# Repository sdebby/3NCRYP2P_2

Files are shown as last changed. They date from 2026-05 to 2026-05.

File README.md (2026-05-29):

# LoRaCore - 3NCRYP2P V2

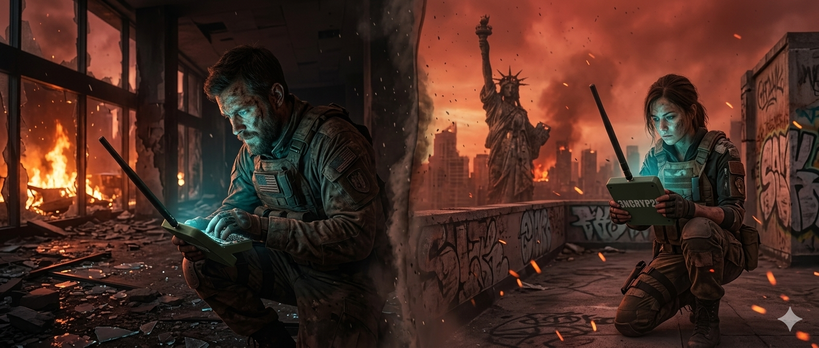
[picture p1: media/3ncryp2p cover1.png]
Overview picture


**When the towers fall, the grid dies, and the satellites stop answering, two of these still talk to each other.**

## Overview

This repository is the forking UPGRADED from the original [sdebby/3NCRYP2P](https://github.com/sdebby/3NCRYP2P) project, refactored under the working name **LoRaCore**.

LoRaCore is the firmware for **3NCRYP2P** (ENCRYPT P2P) - a portable, off-grid, end-to-end encrypted peer-to-peer messaging terminal. It is built around the ESP32-C6, an SSD1306 OLED, a CardKB keyboard, and a 433 MHz LoRa transceiver. No cell tower. No internet. No cloud account. No subscription. Two devices, a pair of public keys, and validated 1.5 km in metropolitan .

---

## In a nutshell

- **Encrypted text messaging over LoRa** at 433 MHz, AES-256 in CTR mode, with HMAC-SHA256 message authentication.
- **Diffie-Hellman key exchange (Curve25519)** so the long-term shared secret is never transmitted, never stored on memory in plaintext, and never reused between sessions.
- **Pairing over ESP-NOW**, a short-range link used only at first introduction. The plaintext public keys and MAC are exposed only to anything within roughly 100 metres line-of-sight in that brief window.
- **At-rest hardening**: the remote device's MAC is persisted only as a salted SHA-256 digest. A flash dump alone does not yield the peer identity or a usable HMAC input.
- **Replay and tamper resistance** through random 16-byte IVs per packet and HMAC verification on every frame, including ACKs.
- **Brute-force lockout**: 10 consecutive HMAC failures permanently lock the device until the operator resyncs keys.
- **Reliable delivery** via a 3-attempt retry loop with 2 second ACK timeout per attempt.
- **Local UI**: 128x64 OLED with 20-line scrollback, full QWERTY input via CardKB, scroll using Up/Down keys, dedicated Fn+K key combination to re-pair.

## MRD (Marketing Requirement)

- Provide a simple, secure, and portable LoRa-based communication terminal.
- Support up to *20* lines of message history on a compact OLED display.
- Enable secure key exchange and encrypted messaging between devices.
- Top notch security using AES-256 in CTR mode, with HMAC-SHA256 message authentication, Diffie-Hellman key exchange (Curve25519) and short range MAC address exchange.
- Allow easy user input and message reading.
- Feedback for system status and errors using debug.
- Military look-alike enclosure 😊.

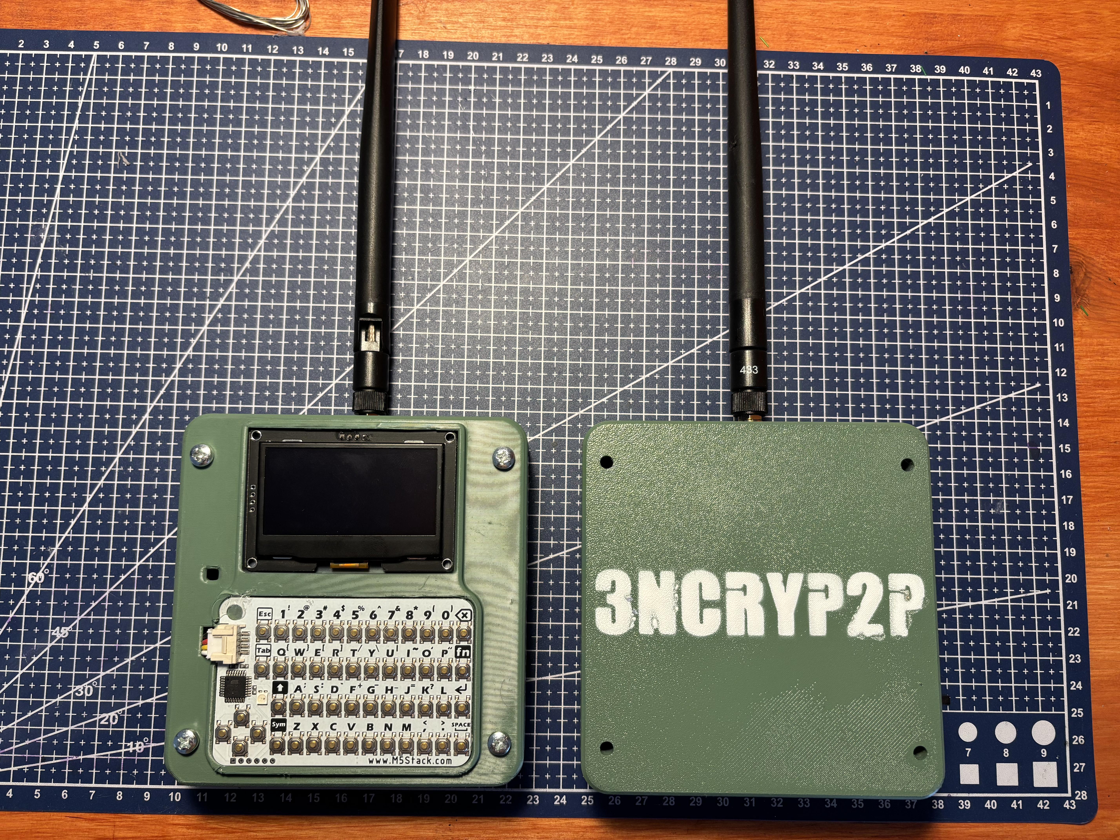
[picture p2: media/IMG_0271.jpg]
Device Overview

 
 ## Skill Set

- Embedded C++ programming (Arduino/ESP32).
- LoRa wireless communication.
- ESP NOW communication protocol.
- Cryptography (AES256 CTR, Diffie-Hellman, HMAC, Hasing remote MAC address).
- 3D design.
- 3D printing and painting.

## Setup (Software Setup)

**Hardware Requirements:**
| Component | Detail |
|---|---|
| MCU | ESP32-C6 |
| Radio | LoRa SX1278 module, 433 MHz |
| Display | SSD1306 OLED, 128 x 64 px, I2C address 0x3C |
| Keyboard | M5Stack CardKB, I2C address 0x5F |
| Status LED | Builtin LED |
| Enclosure | PETG 3D-printable - design using Fusion 360, source files in `CAD/` |

## BOM (Bill Of Materials):

**For production:**
1. ESP32 C6 dev kit
2. [LoRa RA02](https://docs.ai-thinker.com/_media/lora/docs/c048ps01a1_ra-02_product_specification_v1.1.pdf) (433 MHz module)
3. [SSD1306 OLED - 2.24 inch I2C](https://tcclcd.en.made-in-china.com/product/swOajivDfxpf/China-2-42-Inch-128-64-LCD-SSD1309-Driver-Yellow-Monochrome-OLED-Display.html) (128x64 pixels, I2C)
4. [CardKB keyboard](https://docs.m5stack.com/en/unit/cardkb_1.1) (I2C)
5. [Charger panel](https://www.aliexpress.com/item/1005005037876729.html?spm=a2g0o.order_list.order_list_main.386.6b881802CcDzO8)
6. [433 MHz antenna] (https://he.aliexpress.com/item/1005009824013771.html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).
7. LiPo battery 850 mAh.
8. On/Off switch.
9. Custom PCB manufacturing using JLCPCB.
10. 3D printing for enclosure.
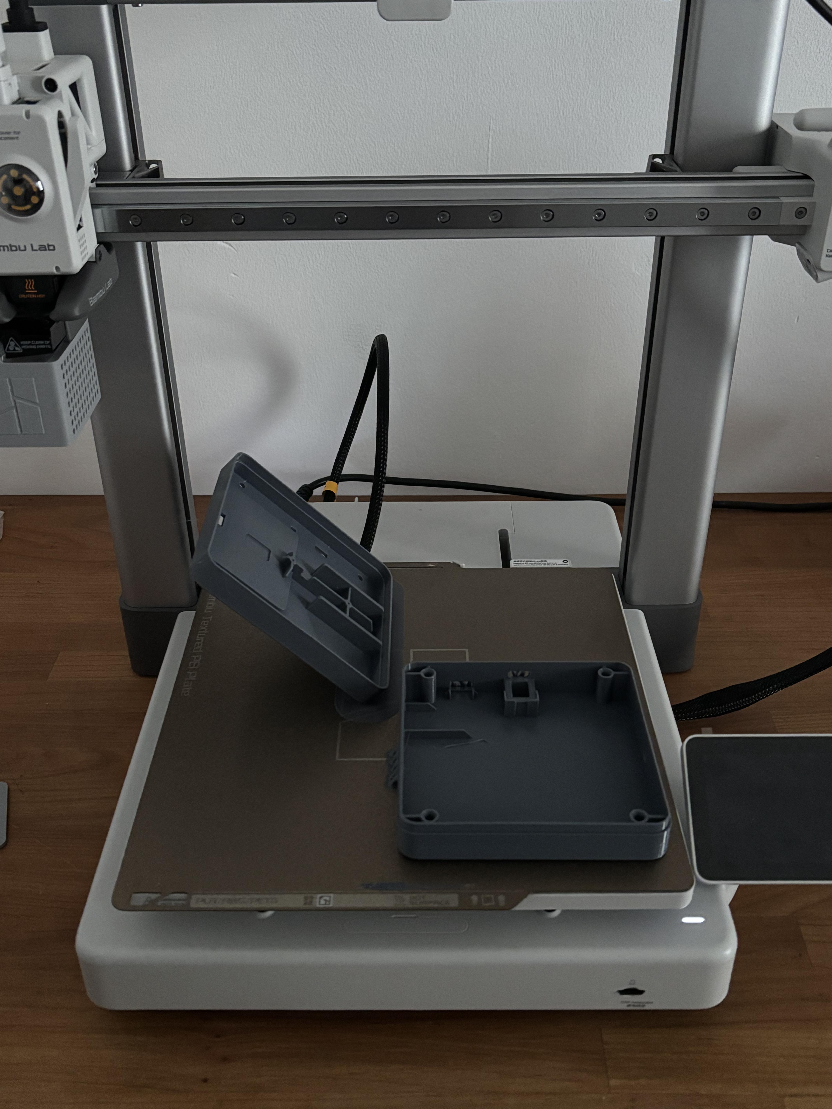
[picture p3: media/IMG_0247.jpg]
3D printing enclosure - from PETG


## Cryptographic stack

```
Pairing  : Curve25519 ECDH  ->  shared secret  ->  SHA-256  ->  32-byte session key (HashSecret)
Identity : SHA-256( MAC || HashSecret )  -> 32-byte salted MAC digest, persisted in NVS
Confidentiality : AES-256-CTR( HashSecret, random 16-byte IV per packet )
Integrity / authenticity : HMAC-SHA256, key = HashSecret, input = ciphertext || IV || senderMacDigest
ACK integrity : HMAC-SHA256 over the 3-byte return code, same key derivation
Replay defence : fresh random IV per packet, included in HMAC input
Lockout : 10 consecutive HMAC failures sets DevLock = true in NVS, requires re-pair
```

The session key (`HashSecret`) is held in RAM only. It is never written to flash. A power cycle on either device forces a fresh handshake over LoRa using the previously paired peer, and a Fn+K from the operator forces a full re-pair over ESP-NOW.

---

## LoRa packet format

```
[Setup 1B] [PayloadSize 1B] [Payload N B] [IV 16B] [HMAC 32B]
```

| Setup bit | Meaning |
|---|---|
| 0 | Handshake - public key + sender MAC + key-return flag |
| 1 | Test message - decryption sanity check after handshake |
| 2 | Encrypted user message |
| 3 | ACK / NACK - return codes 200 OK, 502 NACK, 500 RESYNC |

---

## File map

| File | Role |
|---|---|
| `LoRaCore.ino` | Main entry. Defines globals, pinout, screen and keyboard setup, the state machine, the `setup()` and `loop()` functions, keyboard handling (Enter, Backspace, Up, Down, Fn+K, Fn+D), the ESP-NOW broadcast peer class, the boot-time decision tree between fresh pairing and resuming an existing pair, and the optional Auto Interval Messages debug sender. |
| `LoRaHelper.ino` | Everything LoRa: radio parameter setup (frequency, bandwidth, spreading factor, coding rate, sync word, TX power), `SendLoRaPayload` for encrypting and transmitting a frame, `SendWithRetry` for the 3-try / 2 s ACK loop, `TransmitLoRaPayload` and `TransmitLoRaACK` and `TransmitLoRaHandshake` for the wire-format writers, and the receive-side `onReceive` switch that dispatches handshake, test, encrypted, and ACK frames - including HMAC verification, lockout counter, and ACK reply. |
| `EncryptHelper.ino` | All cryptographic primitives: Curve25519 keypair generation (`CalcKeys`), peer key processing and shared-secret computation (`computeSharedSecret`, `RemoteKeyReceivedProcess`), session-key derivation via SHA-256 (`CalculHashSecret`), random IV generation, AES-256-CTR encrypt and decrypt, and the raw HMAC-SHA256 calculation. |
| `EspNowHelper.ino` | Short-range pairing transport: Wi-Fi STA setup on channel 6, `ExchangePublicKeysESPNOW` which broadcasts the local public key up to `KeySendTries` times on a 2 s scheduler, and the post-pairing trigger that fires the LoRa test payload from whichever peer has the larger MAC (deterministic tie-break to prevent both devices transmitting simultaneously). |
| `displayHelper.ino` | OLED rendering: display init, `printSCR` which prefixes outgoing (`->`), incoming (`<-`), and system (`* `) messages and word-wraps them into the 20-line scrollback buffer, scroll-up and scroll-down for history navigation, the input-line separator, and the boot logo. |
| `generalHelpers.ino` | Persistence, identity, and integrity glue: NVS preferences setup under namespace `3NCRYPT2P`, legacy migration that strips any plaintext `RemoteMAC` key, the lockout loop that drives the LED red and halts the device, the salted MAC hashing function, the HMAC input builder (ciphertext || IV || macDigest), and the local MAC reader. |
| `Jurnal.md` | Development journal. Chronological design notes from March 2025 onwards: why ESP-NOW was picked over Zigbee, Thread, NFC, BLE and serial; the move from a hardcoded key to Curve25519 ECDH; the move from SHA-256 message digests to HMAC-SHA256; the move from AES-128 to AES-256; the hybrid pair-once-over-ESP-NOW, rekey-each-boot-over-LoRa scheme; bug fixes and feature additions through to spring 2026. |
| `CAD/` | 3D-printable enclosure parts. SolidWorks part file and neutral STEP export for the 2.42-inch OLED carrier. |
| `CLAUDE.md` | Internal project notes used by AI assistants when working on this codebase. Not required for build. |

---

## Build and flash

1. Clone or download this repository.
2. Install the **Arduino IDE** with **ESP32 board support**.
3. Install these libraries through the Library Manager:
   - `LoRa` (Sandeep Mistry)
   - `Adafruit SSD1306` and `Adafruit GFX`
   - `Adafruit NeoPixel`
   - `Crypto` (provides `Curve25519.h`, `SHA256.h`, `AES.h`, `CTR.h`)
   - `ptScheduler`
1. Open `LoRaCore.ino` in the Arduino IDE. The other `.ino` files in this folder are picked up automatically as part of the same sketch.
2. Select board: **ESP32-C6 Dev Module**.
3. Optional: set **Tools -> Core Debug Level -> Debug** to enable the verbose serial console (`Consl = true`) and accept text input over the serial port instead of the keyboard.
4. Compile and upload. Repeat for the second unit.

---

## First-time pairing

1. Power on both devices in the same room.
2. With no remote stored in NVS, each device automatically enters ESP-NOW broadcast mode and exchanges public keys.
3. The device with the larger MAC (deterministic, computed from each side's WiFi STA MAC) sends an AES-256 encrypted test payload over LoRa. The receiver decrypts, verifies HMAC, and the screen confirms `Key exchange process success`.
4. Both devices now show `SYSTEM READY!`. The salted remote-MAC digest is written to NVS. The session key lives only in RAM.

To force a re-pair at any time, press **Fn+K** on the keyboard, then press **ENTER** when the remote operator confirms readiness on their unit.

---

## Daily use

| Action | Key |
|---|---|
| Send the typed message | ENTER |
| Delete the previous character | BACKSPACE |
| Scroll back through history | UP arrow |
| Scroll forward through history | DOWN arrow |
| Force a full re-pair (ESP-NOW) | Fn + K |
| Toggle Auto Interval Messages (debug) | Fn + D |

Outgoing messages are prefixed with `->`. Incoming with `<-`. System messages with `* `. Up to 20 lines of history are kept; six lines are visible at a time on the 128x64 display.

---

## Threat model and known weak points

What this device defends against:

- A passive eavesdropper anywhere along the LoRa path. Without `HashSecret` the traffic is AES-256 ciphertext with random IVs.
- An active attacker injecting forged messages. HMAC-SHA256 over ciphertext, IV, and the sender's salted MAC digest will fail verification, the message is dropped, and the failure counter increments.
- A flash-dump attacker with physical access to one device after the fact. Only the salted MAC digest is on disk; the session key is not.
- Brute-force probing. After 10 consecutive HMAC failures the device permanently locks until re-pair.

What this device does **not** defend against:

- An attacker physically present during the **initial ESP-NOW pairing**. Within roughly 100 metres of the pairing event, the public keys and MAC are observable. This is a short, deliberately bounded window. The original 3NCRYP2P also flagged this as the system's Achilles heel; the move from hardcoded keys to ECDH closed the more serious version of that problem, but pairing-time exposure remains.
- A compromised endpoint. If the attacker holds your device while it is unlocked and paired, they hold the conversation.
- Side-channel attacks against the ESP32-C6 itself.
- Direction-finding. LoRa transmissions are emissions; they can be located by anyone with an SDR and patience. Encryption protects content, not the fact that you are transmitting.

Plan accordingly.

---

## Range

Tested up to **1.5 km** in  urban conditions with the parameters in this firmware. Open terrain, elevation on either end, or a directional antenna will extend that. Heavy concrete, dense forest, or a hill in the middle will shorten it.

---
## Schematics

Scheme

## PCB

* PCB design using KiCad
* 2 layers PCB, black color.
* PCB manufacturing using JLCPCB
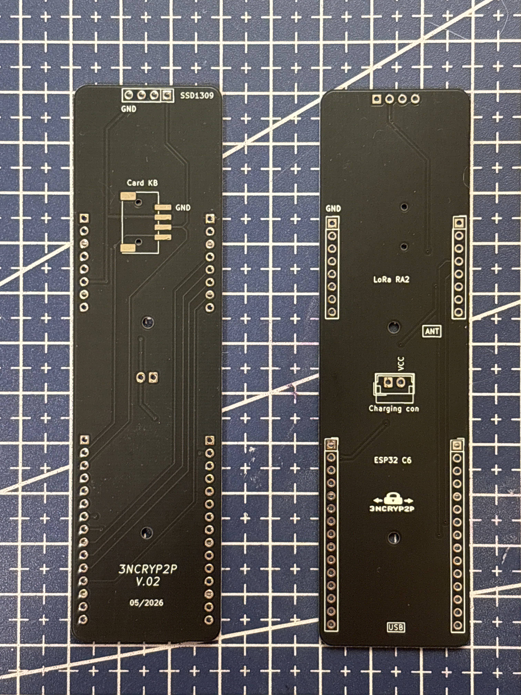
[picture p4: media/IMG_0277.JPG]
Custom PCB

you can download the gerber files from /GERBER Library
---

## Hardware assembly:

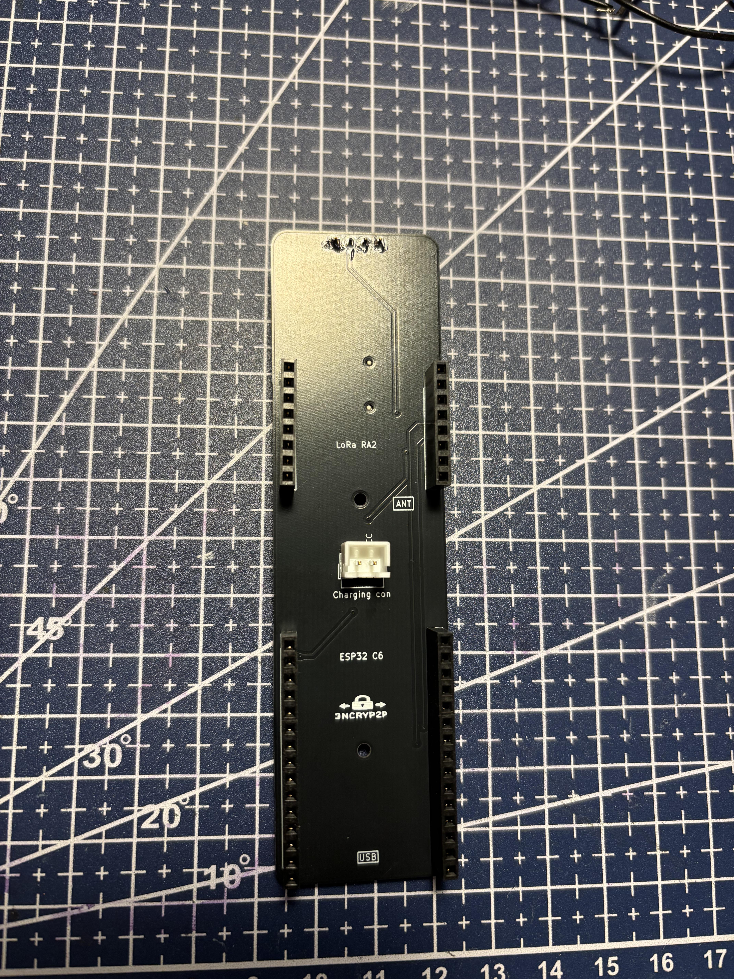
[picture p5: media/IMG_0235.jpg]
PCB Soldering 1


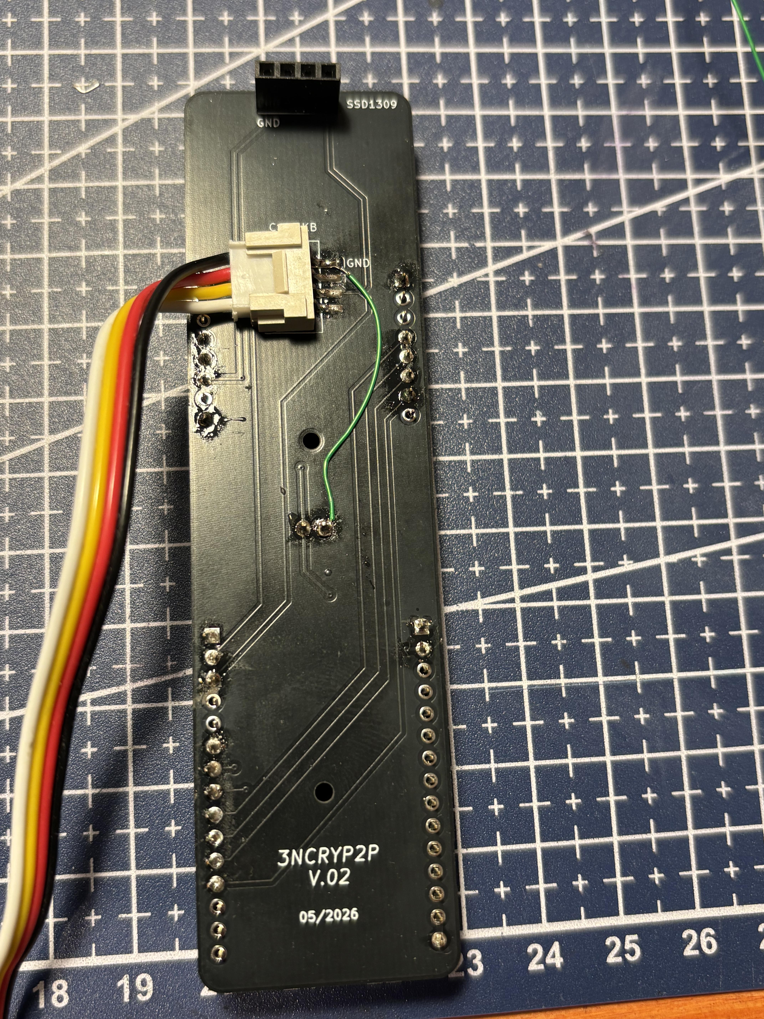
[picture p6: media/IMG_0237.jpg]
PCB Soldering 2


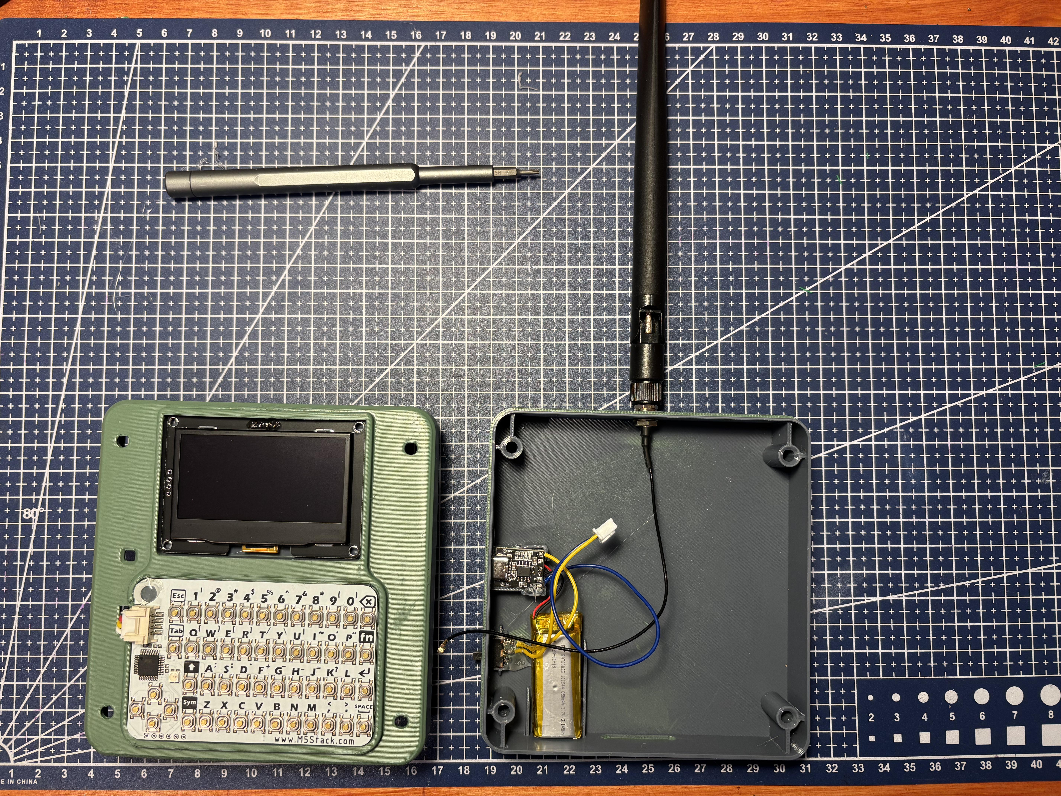
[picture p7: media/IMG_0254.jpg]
Assembly on enclosure 1


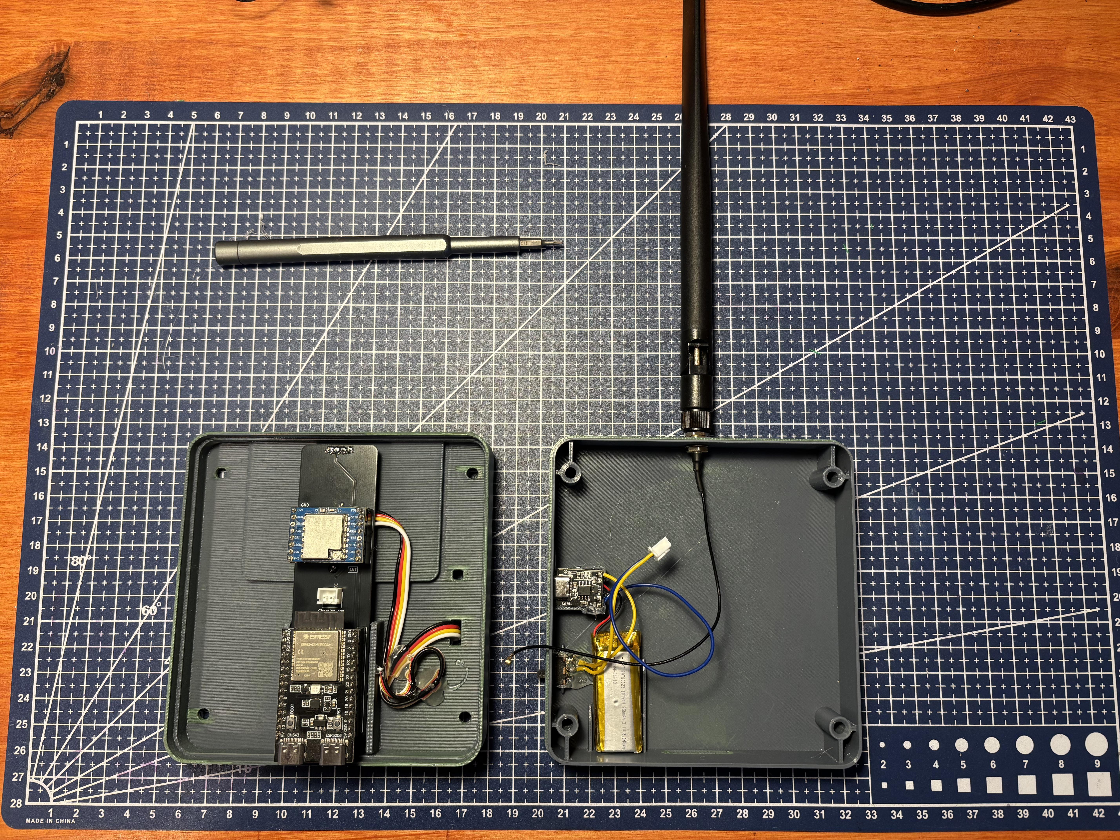
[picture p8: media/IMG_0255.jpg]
Assembly on enclosure 2


### 3D enclosure design

* Using Autodesk Fusion360
* 3D print using Bambulab A1 with PETG filament.
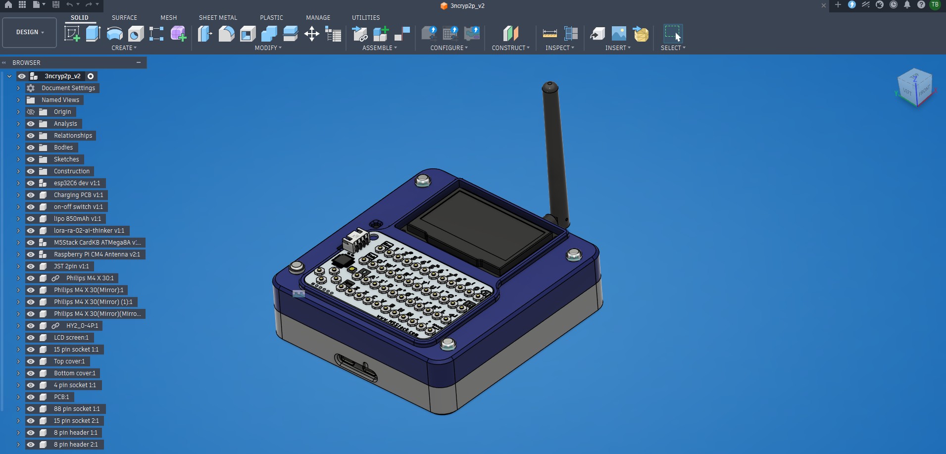
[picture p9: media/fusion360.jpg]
Fusion360 Design

you can download the 3D files from /3D library.

Painting 
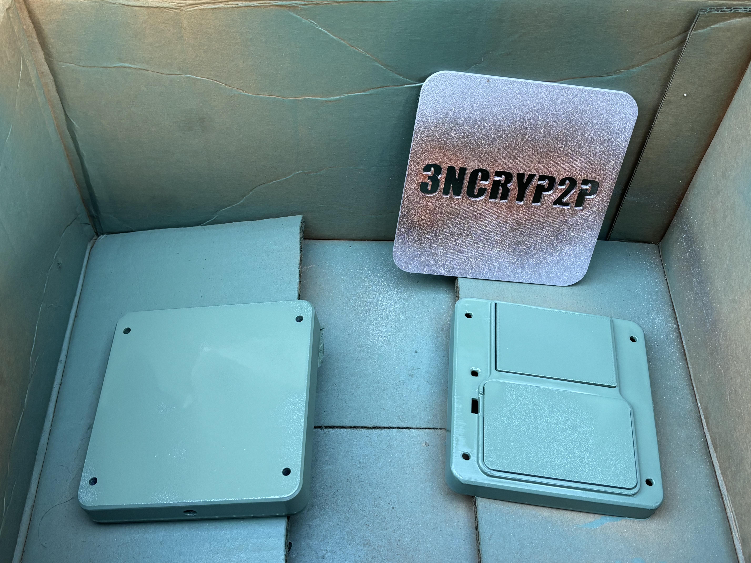
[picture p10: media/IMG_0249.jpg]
Paint 1


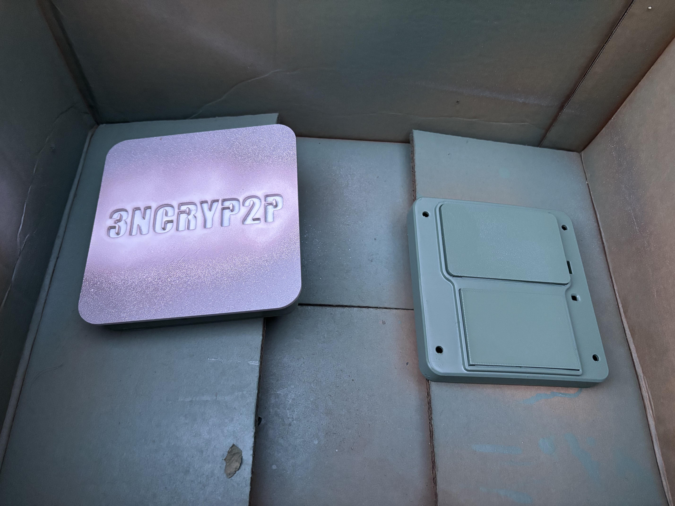
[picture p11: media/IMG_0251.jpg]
Paint 2


## Range test
**Sender**

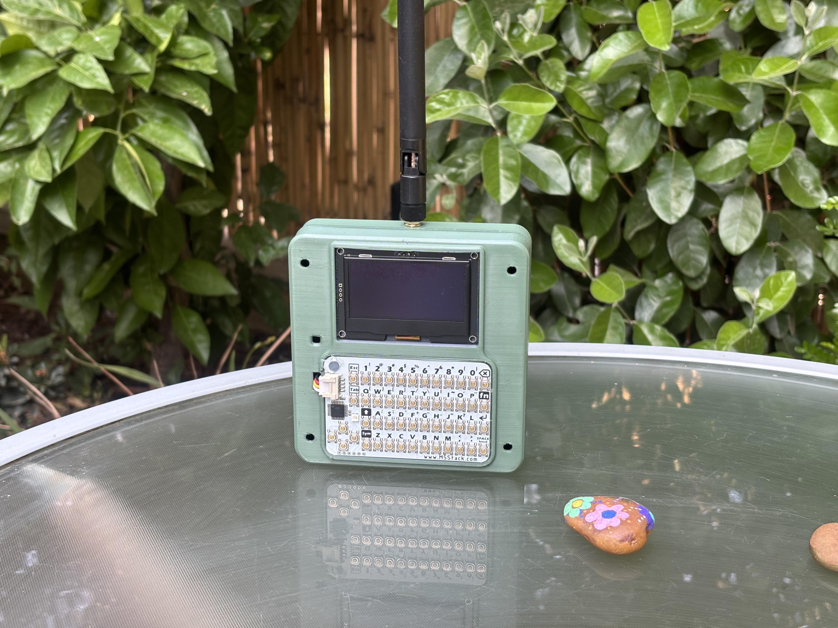
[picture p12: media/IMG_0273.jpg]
Sender


---

**Receiver**

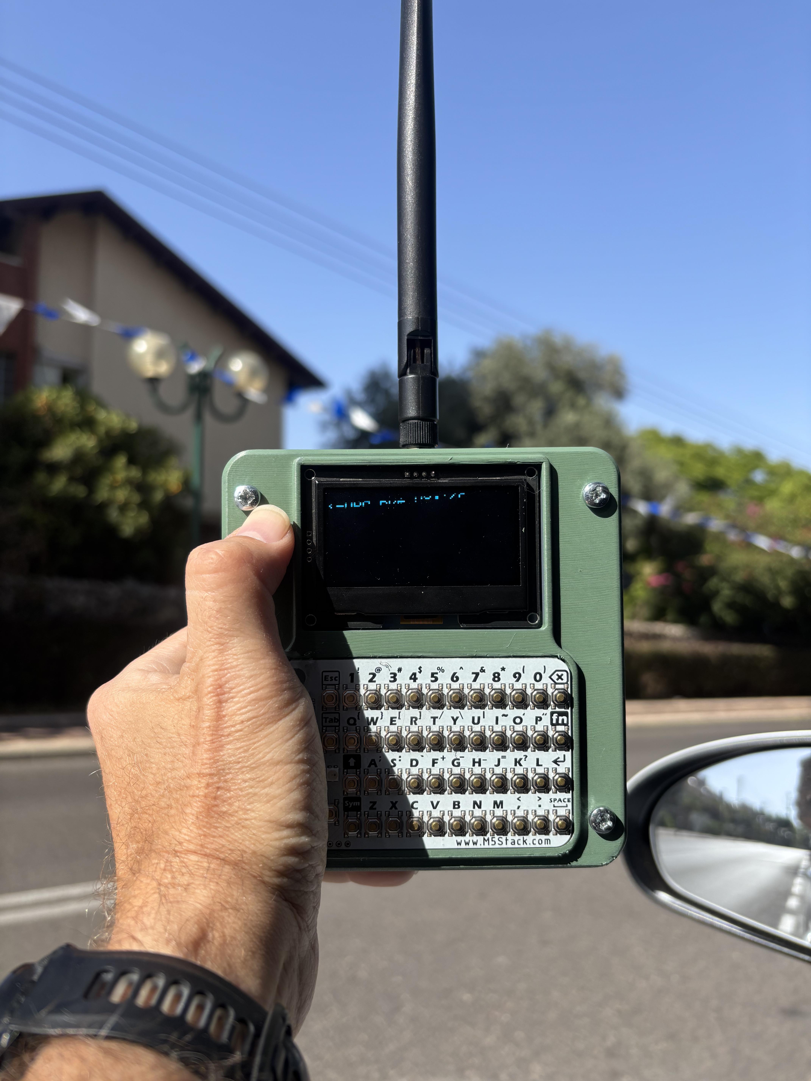
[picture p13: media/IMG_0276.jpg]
Receiver


**Non-line of sight distance** 1.5 Km

## Power consumption

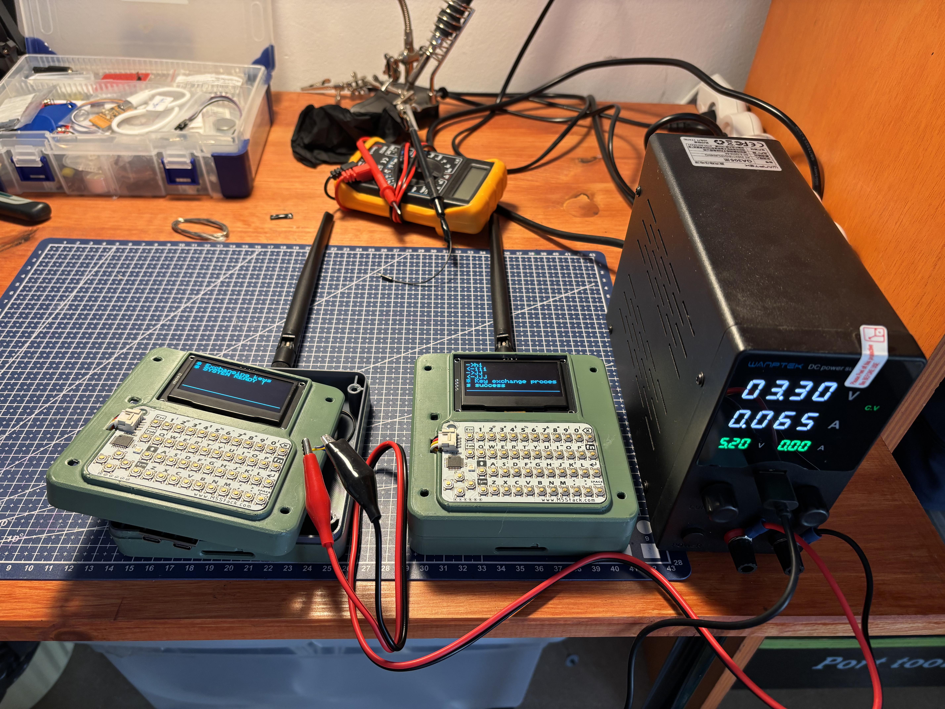
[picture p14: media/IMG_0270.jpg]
Checking power


- Battery capacity: 850 mAh
- Idle current: 65 mA (continuous)
- Hourly burst: +162 mA for 25 s (sending 25 messages an hour)
- Startup: 180 mA for 3 s (one-time) (ESP NOW sync)

Average hourly consumption
65 + 1.125 = 66.125 mAh / hour
Usable capacity after startup: 850 − 0.15 = 849.85 mAh
t = 849.85 ÷ 66.125 ≈ 12.85 hours ≈ 12 h 51 min

**Suggestion for optimization**
putting Display on sleep when ideal.
adding LED to display when new message arrives, then the user will press any button to wake up the screen. 

## Video

(https://youtu.be/NzuQNOC-KOk)

## Compare to 3NCRYP2P V1

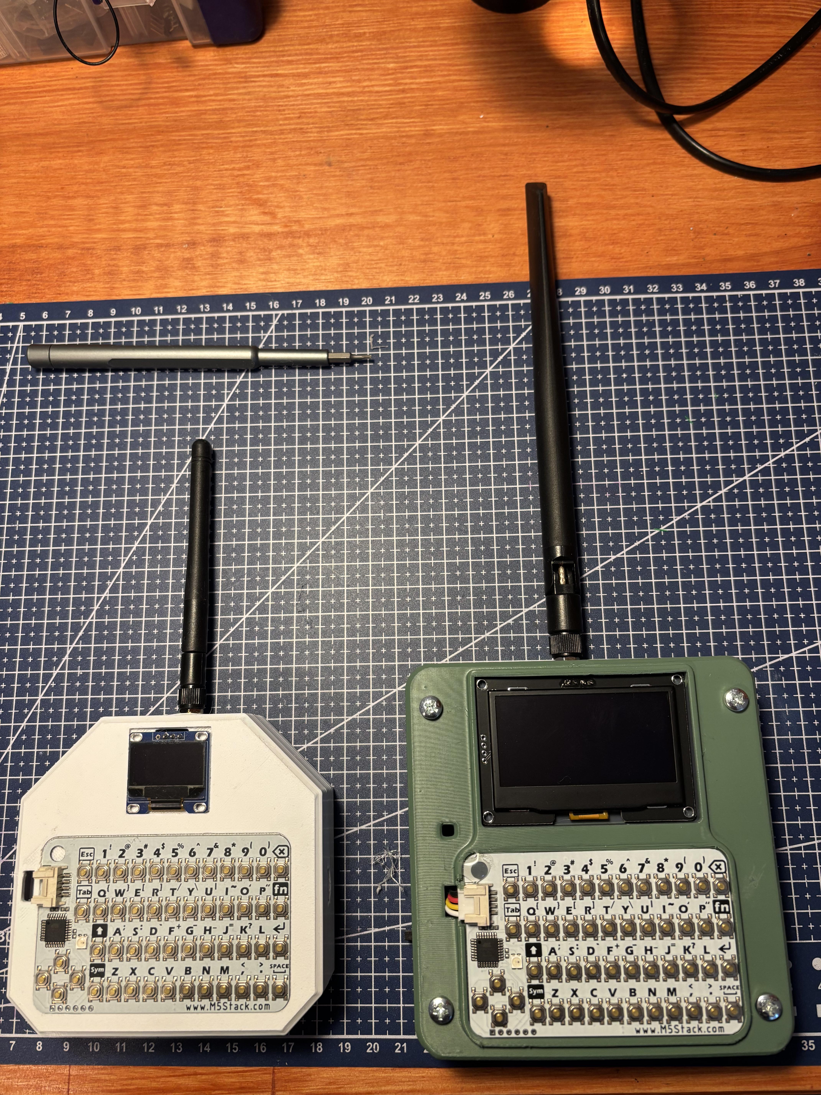
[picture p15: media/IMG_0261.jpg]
Design Compare 1


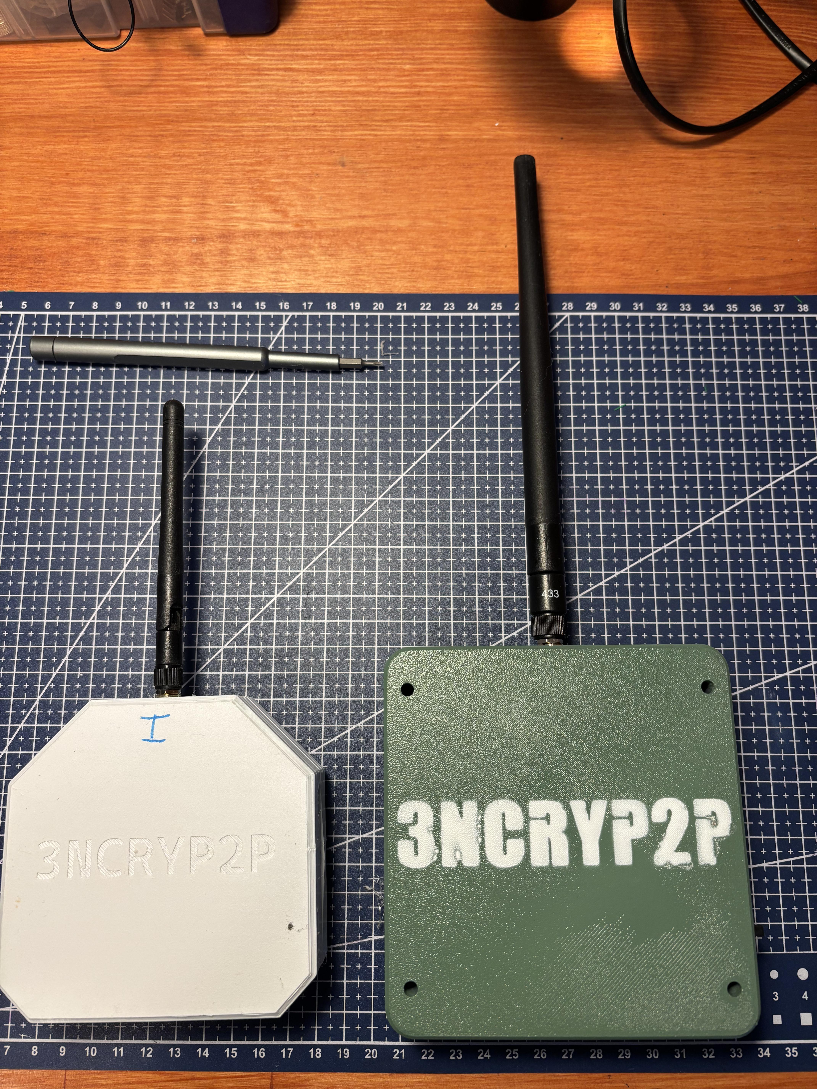
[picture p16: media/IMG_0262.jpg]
Design Compare 2


* BETTER ENCRYPTION - breaking V1 Achilles heel - using AES256 asymmetric key encryption.
* HMAC message validation - including device secret MAC address.
* Device MAC address is exchanged in short range only and hashed in device memory.
* A longer (18 cm with 3dbi gain instead of 9 cm) antenna is improving the range from 500 m in urban area to 1.5 Km.
* Military looking device.
* bigger screen (2.42" instead of 1.3")

## Compare to MESHTASTIC project

[Meshtastic](https://meshtastic.org/)
- LoRaCore is a strict **1:1 encrypted terminal**
- Meshtastic is a **many-to-many community mesh**. The table below summarizes the trade-offs.

### Feature comparison

| Area | LoRaCore (3NCRYP2P V2) | Meshtastic |
|---|---|---|
| Network topology | Strict 1:1 paired devices | Multi-hop mesh, many nodes |
| Key exchange | Curve25519 ECDH at pairing, ephemeral per session | Pre-shared channel key (PSK); x25519 PKC added for DMs in v2.5+ |
| Session key storage | RAM only, never on flash | PSK persisted on flash per channel |
| Confidentiality | AES-256-CTR, random 16 B IV per packet | AES-256-CTR (channels), AES-CCM (DMs since v2.5) |
| Message authentication | HMAC-SHA256 on every packet (incl. ACKs) | None on channel messages; AES-CCM tag on DMs only |
| Sender identity binding | Salted SHA-256 MAC digest mixed into HMAC | None - anyone with PSK can impersonate any node |
| Replay defence | Random IV + HMAC per packet (no counter window) | Packet-ID dedup, short window |
| Forward secrecy | Effective (re-pair regenerates keys, key never written to flash) | None - "Harvest now, decrypt later" is acknowledged in their docs |
| Brute-force lockout | Yes - 10 HMAC failures permanently locks NVS | None |
| At-rest hardening | Only salted MAC digest persisted | PSK, node DB, position history persisted |
| Range per hop | ~1.5 km validated urban, 433 MHz | Similar per hop (varies by band/region) |
| Effective reach | Single hop only | Multi-hop, region-wide with enough nodes |
| Frequency band | 433 MHz (fixed at compile time) | 433 / 868 / 915 MHz, region-configurable |
| User interface | Standalone - built-in OLED + CardKB, no phone needed | Phone app (BLE/Wi-Fi) on most devices; few have native KB/screen |
| Hardware support | One purpose-built ESP32-C6 design | Dozens: T-Beam, Heltec V3, T114, RAK WisBlock, Wio Tracker, etc. |
| Attack surface | LoRa + ESP-NOW only, no IP stack, no BLE, no MQTT | LoRa + BLE + Wi-Fi + MQTT + web admin + OTA |
| Code base size | ~6 short `.ino` files, auditable in an afternoon | Large C++ codebase, many subsystems |
| Ecosystem & community | Personal project, single maintainer | Large open-source community, active CVE tracking |
| Power budget | ~66 mA average, ~12.85 h on 850 mAh | Varies; nRF52 boards (e.g. T114) reach ~11 µA deep sleep |
| Group messaging | Not supported by design | Native - channels and groups |
| GPS / telemetry | Not included | Built-in on many boards (position, battery, env sensors) |
| Setup effort | Two pre-paired units, no config | Phone pairing, channel keys, region selection |

## Next steps
[ ] Increase range with a directional antenna ,higher gain or mesh communication.

[ ] Increase partners.

## A note for whoever finds this later

If you are reading this and the rest of the network is gone, the recipe is in the files.

**Do not panic !**

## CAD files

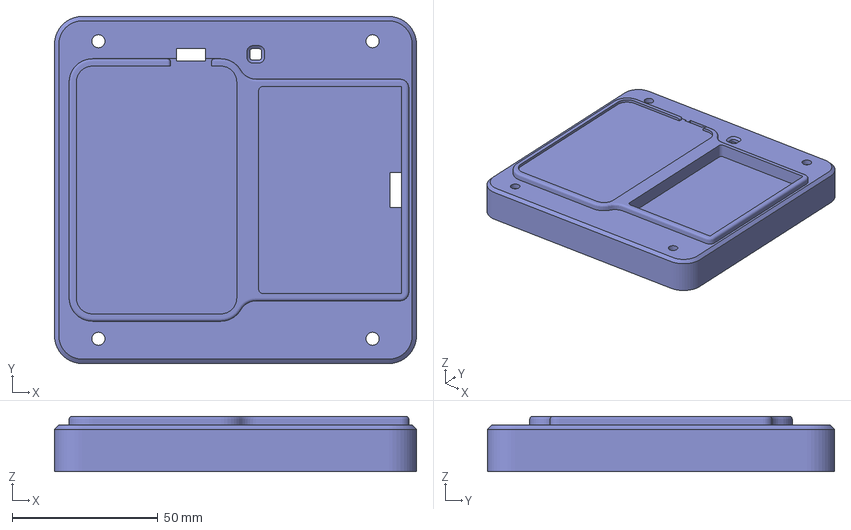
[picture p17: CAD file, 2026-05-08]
3D/260506 Top cover.3mf
124.1 x 119.0 x 19.0 mm

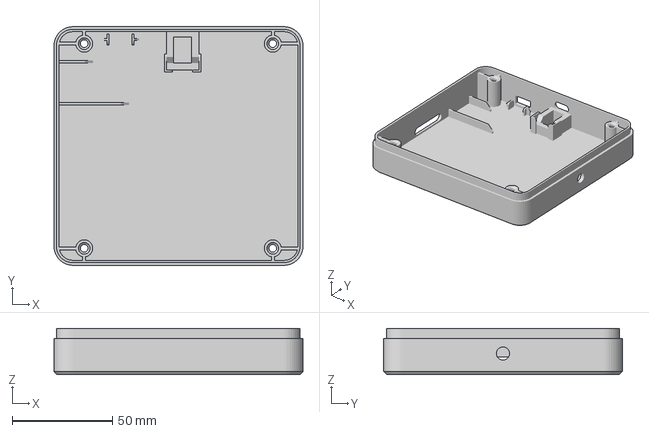
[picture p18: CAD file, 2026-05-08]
3D/260508 Bottom cover.3mf
124.1 x 119.0 x 23.0 mm

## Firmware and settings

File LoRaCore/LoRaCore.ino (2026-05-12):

/* 27.02.2026
3NCRYPT2P project
__ Omni Screen and keyboard program __
__ Enhance security ___

*/
#define SoftwareVer 260501
#include <SPI.h>
#include <LoRa.h>
#include <Preferences.h>
#include "esp32-hal-log.h"
#include <Adafruit_NeoPixel.h> //for internal LED
  constexpr uint8_t LED_PIN = 8;
  constexpr uint8_t NUM_LEDS = 1;
#include "ptScheduler.h"

// Define screen and keyboard
#include <Wire.h>
#include <Adafruit_SSD1306.h>

#define CARDKB_ADDR 0x5F 
#define SCRN_ADDR 0x3C 

// Define screen width and height
#define SCREEN_WIDTH 128
#define SCREEN_HEIGHT 64
#define MAX_LINES 6  // Maximum number of lines that can fit on screen
#define LINE_HEIGHT 8  // Height of each line in pixels
#define LINE_BUFFER 20 // Total history lines preserved

Adafruit_SSD1306 display(SCREEN_WIDTH, SCREEN_HEIGHT, &Wire, -1);
int TextSize = 1;
String lines[LINE_BUFFER];  // Array to store history lines
int totalLines = 0;          // How many lines written so far
int scrollOffset = 0;        // Scroll position (0 = newest visible)
int currentLine = 0;         // Current line position

#if CONFIG_IDF_TARGET_ESP32C6  // Define LoRa-ESP32 pin out for ESP32 - C6
  #define BoardMSG  "[*] ESP32-C6 board found"
  #include <WiFi.h>
  #define ss 18
  #define rst 23
  #define dio0 22
  #define WireSDA 3
  #define WireSCL 2

#elif CONFIG_IDF_TARGET_ESP32S3
  #define BoardMSG "[*] ESP32-S3 board found"

#else
  #error "[X] The code will run on ESP32 C6 only."
#endif

#define MAX_PAYLOAD_SIZE 255
#define KEY_ENTER 13
#define KEY_BACKSPACE 8
#define KEY_UP 181
#define KEY_DOWN 182
#define KEYBOARD_KEY_EXCHANGE 161 //function + k
#define KEYBOARD_KEY_AIM 156 //function + d (DEBUG)

bool Consl = false; // Console/debug mode
bool AIM = false; // AIM = Automated Interval Messages

bool SendFirst = false; // send sequence = true if LocalMacInt_global > RemotemacInt)

  // Define Encryption key
  uint8_t sharedA[32]; //Shared secret
  uint8_t publicKey[32];
  uint8_t privateKey[32];
  uint8_t HashSecret[32];
  // Debug - send messages in intervals
  int counter = 0;
int ReceiveErrorCount = 0;  // Count of failed HMAC verification on received messages
const int MAX_RECEIVE_ERRORS = 10;

String ReceivedMSG_Pack = "";
const int RTN_OK = 200;
const int RTN_NG = 502;
const int RTN_RESYNC = 500;
bool ackReceived = false;       // Flag set by ACK handler (case 3)
const int SEND_RETRIES = 3;     // Max send attempts
const int ACK_TIMEOUT_MS = 2000; // Wait time for ACK per attempt

Preferences preferences;
String PayloadInput = "";
String ReSendPayloadInput = "";


// Saved parameters under 3NRYP2P project
String DevLock = "DeviceLOCK";
String RemoteMAC = "RemoteMAC";          // legacy plaintext key, removed on boot if present
String RemoteMACHash = "RemoteMACH";     // 32-byte salted SHA-256 of remote MAC
uint64_t RemotemacInt = 0;               // RAM only; populated during pairing, used for send-order compare
uint64_t LocalMacInt_global = 0;
uint8_t  RemoteMacHashed[32] = {0};      // SHA-256(remoteMac || HashSecret)
uint8_t  LocalMacHashed[32]  = {0};      // SHA-256(localMac  || HashSecret)
bool     RemotePaired = false;           // true once RemoteMACHash blob is loaded/written
String TestPayload = "CONFIRM";
bool TestPayloadSent = false; //test payload sent flag
int KeySendCounter = 0;
int KeySendTries = 3;
bool RemoteKeyReceived = false; // Remote public key received flag
ptScheduler PubKeySendTimer = ptScheduler (PT_TIME_2S); 
ptScheduler AIMInterval = ptScheduler (PT_TIME_10S);
Adafruit_NeoPixel rgbLed(NUM_LEDS, LED_PIN, NEO_GRB + NEO_KHZ800);
struct RGB {
    uint8_t r, g, b;
};
constexpr RGB COLOR_OFF   = {0, 0, 0};
constexpr RGB COLOR_RED = {255, 0, 0}; 

// ESP NOW - begin
#include "ESP32_NOW.h"
#include "WiFi.h"
#include <esp_mac.h>  // For MAC2STR and MACSTR macros

#define ESPNOW_WIFI_CHANNEL 6

/* Set RGB colors in built in led
*/
void setLEDColor(const RGB& color, uint8_t brightness = 100) {
  uint16_t scale = (uint16_t)brightness * 255 / 100;
  uint8_t r = (uint8_t)(((uint16_t)color.r * scale) / 255);
  uint8_t g = (uint8_t)(((uint16_t)color.g * scale) / 255);
  uint8_t b = (uint8_t)(((uint16_t)color.b * scale) / 255);
  rgbLed.setPixelColor(0, rgbLed.Color(r, g, b));
  rgbLed.show();
}

class ESP_NOW_Broadcast_Peer : public ESP_NOW_Peer {
public:

  ESP_NOW_Broadcast_Peer(uint8_t channel, wifi_interface_t iface, const uint8_t *lmk)
    : ESP_NOW_Peer(ESP_NOW.BROADCAST_ADDR, channel, iface, lmk) {}

  ~ESP_NOW_Broadcast_Peer() {
    remove();
  }

  bool begin() {
    if (!ESP_NOW.begin() || !add()) {
      Serial.println("[X] Failed to initialize ESP-NOW or register the broadcast peer");
      return false;
    }
    return true;
  }

  bool send_message(const uint8_t *data, size_t len) {
    if (!send(data, len)) {
      Serial.println("[X] Failed to broadcast message");
      return false;
    }
    return true;
  }

  // Override onReceive to handle incoming messages
  void onReceive(const uint8_t *data, size_t len, bool broadcast) override {
    Serial.printf("[V] (onReceive) Received a message from " MACSTR " (%s)\n", MAC2STR(addr()), broadcast ? "broadcast" : "unicast");
  }
};

ESP_NOW_Broadcast_Peer broadcast_peer(ESPNOW_WIFI_CHANNEL, WIFI_IF_STA, nullptr);

// Callback function to handle incoming messages from unknown peers
void onNewPeer(const esp_now_recv_info_t *info, const uint8_t *data, int len, void *arg) {
  RemotemacInt = 0;  // Reset before calculating
  for (int i = 0; i < 6; i++) {
    RemotemacInt = (RemotemacInt << 8) | info->src_addr[i];
  }
  Serial.printf("[V] (onNewPeer) Received message from " MACSTR " => MAC integer: %llu\n", MAC2STR(info->src_addr), RemotemacInt);
  if (!RemoteKeyReceived){ //Saving first attempt only
    RemoteKeyReceivedProcess(data); //start remote public key process , save remote mac address
    RemoteKeyReceived = true;
    if (LocalMacInt_global > RemotemacInt){
      SendFirst = true;
      Serial.println("[*] Local MAC is larger");
    } else {
      Serial.println("[*] Remote MAC is larger");
    }
  }
} 
// ESP NOW END

void setup() {
  // TODO uncomment this on production !!!
  // if (Consl){
    Serial.begin(115200);
      while (!Serial);
    Serial.printf("**-- 3NCRYP2P CORE - version %d --**\n",SoftwareVer);
  // } else {
  //   Serial.setDebugOutput(false);
  // }
    // Get compiled debug level
  #ifdef CORE_DEBUG_LEVEL
    Serial.printf("[*] CORE_DEBUG_LEVEL Value: %d\n",CORE_DEBUG_LEVEL );// Try printing its value
    #if CORE_DEBUG_LEVEL == 4// if compiled debug level = DEBUG
       Consl = true; 
    #endif
  #else
    Serial.println("[*] CORE_DEBUG_LEVEL is NOT defined.");
  #endif

  // I2C pins
  Wire.begin(WireSDA, WireSCL);
  // Initialize the display
  if (!display.begin(SSD1306_SWITCHCAPVCC, SCRN_ADDR)) {
    Serial.println(F("[X] SSD1309 allocation failed"));
    for (;;);
  }
  intDisp();
  LogoDisplay();
  intPref();
  LocalMacInt_global = GetLocalMAC_int();
  // Check if device is locked
  if (preferences.getBool(DevLock.c_str(),false)){
    LockLoop(); // Lock device
  }
  Serial.println(BoardMSG);

  // Initialize LoRa 
  LoRa.setPins(ss, rst, dio0);
  if (!LoRa.begin(433E6)) {
    log_d("[X] Starting LoRa failed!");
    Serial.println("[X] Rebooting in 3 seconds...");
    delay(3000);
    ESP.restart();
  }
  SetLoRaParam();// LoRa parameters

  /* exchanging public keys via ESP NOW. */
  CalcKeys(publicKey,privateKey);
  if (Consl) preferences.clear(); //DEBUG - clear saved parameters
  size_t blobLen = preferences.getBytes(RemoteMACHash.c_str(), RemoteMacHashed, 32);
  RemotePaired = (blobLen == 32);
  if (!RemotePaired) { //No paired remote stored - start initial handshake
    Serial.println("[X] No paired remote found in preferences, exchanging keys process initiated");
    log_d("[*] ESP NOW - Public key exchange");
    ExchangePublicKeysESPNOW();

  } else { // Paired remote MAC digest in memory
    Serial.println("[*] Paired remote digest found in preferences");
    printSCR("SYSTEM READY !", 0);
    if (isHashSecretZero(HashSecret, sizeof(HashSecret))){ //check if has HashSecret
      printSCR("Exchanging keys", 0);
      TransmitLoRaHandshake(0, 32, publicKey,1);
      } else {
        Serial.println("[*] Hash Secret found in local device");
      }
  }
  rgbLed.begin(); //update built in LED
  rgbLed.show(); 
  setLEDColor(COLOR_OFF); 
}

void loop() {
  onReceive(LoRa.parsePacket());
   if (Consl && Serial.available()) { // Get text from serial if using debug
    PayloadInput = Serial.readStringUntil('\n');
    if (!RemotePaired){
      Serial.println("[X] No paired remote found, run exchange keys process");
      // TODO exit loop and start key exchange via ESP NOW
      delay(500);
    } else {
      if (SendWithRetry(PayloadInput)) {
        printSCR(PayloadInput, 1);
      } else {
        printSCR("No ACK received!", 0);
      }
    }
  } else { // Get text from CardKB
    if (!RemotePaired){
      Serial.println("[X] No paired remote found, run exchange keys process");
      printSCR("Missing remote MAC address, resync public keys",0);
      // TODO exit loop and start key exchange via ESP NOW
      delay(500);
      return;
    } else { //Remote MAC address != 0
      Wire.requestFrom(CARDKB_ADDR, 1);  
      if (Wire.available()) { 
        char c = Wire.read();  // Store the received data.
      if (c != 0) {
          if (c == KEY_ENTER && PayloadInput.length() > 0){  // Enter
            ReSendPayloadInput = PayloadInput; // for re sending payload if needed
            Serial.println(PayloadInput);
            if (SendWithRetry(PayloadInput)) {
              printSCR(PayloadInput, 1);
            } else {
              printSCR("No ACK received!", 0);
            }
            PayloadInput = "";
            } else if (c == KEY_BACKSPACE) {  // Backspace
          int cursorX = display.getCursorX() - 6 * TextSize;
          int cursorY = display.getCursorY();
          if (cursorX < 0) cursorX = 0 ;
          display.setCursor(cursorX, cursorY);
          display.fillRect(cursorX,cursorY,cursorX + 6 * TextSize , cursorY + LINE_HEIGHT * TextSize,BLACK);
          display.display();
          if (PayloadInput.length() > 0) {
            PayloadInput.remove (PayloadInput.length() - 1); // remove last character
          }
          c = 0;
        } else if (c == KEYBOARD_KEY_EXCHANGE){
          Serial.println("[*] ESP NOW key exchange process start");
            display.clearDisplay();
            display.setCursor(0, 0);
            display.println(F("Press ENTER when remote device is ready"));
            display.display();
          while (true) {  // Wait for KEY_ENTER from CardKB
            Wire.requestFrom(CARDKB_ADDR, 1);
            if (Wire.available()) {
              char key = Wire.read();
              if (key == KEY_ENTER) break;
            }
            delay(50);
          }
          //rastart parameters
          TestPayloadSent = false; KeySendCounter = 0; RemoteKeyReceived = false; 
          ExchangePublicKeysESPNOW();
          ESP_NOW.end();
          PayloadInput = "";
        } else if (c ==  KEYBOARD_KEY_AIM){ //change status of AIM - to send/stop auto messaging
          AIM = !AIM;
          printSCR("Start/Stop Auto msg", 0);
        }
        
         else if (c == KEY_UP) {  // Scroll up (older messages)
          scrollUp();
          c = 0;
        } else if (c == KEY_DOWN) {  // Scroll down (newer messages)
          scrollDown();
          c = 0;
        } else {
          PayloadInput += String(c);
          display.print(c);
        }
        display.display();
      }
    } else {
      Serial.println("[X] keyboard not available");
      delay(1000);
    } 
    } 
  }
  if (AIM){
    if (AIMInterval.call()){
      Serial.printf("[*] Sending DEBUG packet: %d \n", counter);
      String Ttext = "DBG PKT No.:" + String(counter);
      printSCR(Ttext,1);
      SendLoRaPayload(2, Ttext);
      counter ++;
    }
  }
  // TODO handle "sync public keys" message show in remote device - if need to sync keys then remote device need to send "resync" return message.
  delay(50);
}

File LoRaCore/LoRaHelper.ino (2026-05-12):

// This is LoRa function helper

  // initialize LoRa parameters
void SetLoRaParam(){
  LoRa.setSyncWord(0xB2);  //Unique Sync Word
  LoRa.setSignalBandwidth(41.7E3); //7.8E3, 10.4E3, 15.6E3, 20.8E3, 31.25E3, 41.7E3, 62.5E3, 125E3, and 250E3.
  LoRa.setSpreadingFactor(9) ;  // Supported values are between `6` and `12`. If a spreading factor of `6` is set, implicit header mode must be used to transmit and receive packets.
  LoRa.setTxPower(20); //2-20 default = 17
  LoRa.enableCrc();  
  LoRa.setPreambleLength(14);
  LoRa.setCodingRate4(8); 
  Serial.println("[*] Sending LoRa initialize parameters.");
}

// Sending test payload to verify key exchange
void SendLoRaPayload(int setupBit , String TextPayload){
        // Generate random IV
  uint8_t* RandIV = generateRandomIV(16);
  if (RandIV) {
      // encrypt payload
    uint8_t ciphertext[TextPayload.length() + 16];  // Add buffer safety margin
    size_t cipherLen = encryptPayload(TextPayload, HashSecret, RandIV, ciphertext); // Encrypt using shared secret and IV return encrypt size
      printHex("[*] Device Encrypted payload: ", ciphertext, cipherLen);
    uint8_t* hmac = HMACHelper(ciphertext, cipherLen, LocalMacHashed, RandIV);
    printHex("[*] Local IV: ", RandIV, 16);
    printHex("[*] Calculated HMAC: ", hmac, 32);
    delay(500); // 0.5S delay
    TransmitLoRaPayload(setupBit, cipherLen, ciphertext, RandIV, hmac);
    free(hmac); 
    free(RandIV); 
  } else {
    Serial.println("[X] Failed to generate random IV");
    printSCR("Cannot generate rnd IV- restart device",0);
  }
}

// Send encrypted payload with retry - wait for ACK up to SEND_RETRIES times
bool SendWithRetry(String TextPayload){
  ackReceived = false;
  for (int attempt = 1; attempt <= SEND_RETRIES; attempt++) {
    Serial.printf("[*] Send attempt %d/%d\n", attempt, SEND_RETRIES);
    SendLoRaPayload(2, TextPayload);
    unsigned long startTime = millis();
    while (millis() - startTime < ACK_TIMEOUT_MS) {
      onReceive(LoRa.parsePacket()); // Poll for incoming ACK
      if (ackReceived) {
        // Serial.println("[V] ACK received");
        return true;
      }
      delay(50);
    }
    Serial.printf("[X] No ACK after attempt %d\n", attempt);
  }
  return false;
}

  // send payload via LoRa
void TransmitLoRaPayload(int Setup,int payloadSize, uint8_t* payload, uint8_t* iv, uint8_t* hmac){
  LoRa.beginPacket();
    LoRa.write(Setup);
    LoRa.write(payloadSize);
    LoRa.write(payload,payloadSize);
    LoRa.write(iv,16);
    LoRa.write(hmac,32);
  LoRa.endPacket();
}
// Send ACK - setup bit 3 | rtn[3] | IV[16] | HMAC[32]
// HMAC key = HashSecret, HMAC input = rtn + length(3) + LocalMAC + IV
void TransmitLoRaACK(int rtn){
  uint8_t* RandIV = generateRandomIV(16);
  if (!RandIV) {
    Serial.println("[X] Failed to generate IV for ACK");
    return;
  }
  String rtnStr = String(rtn);
  uint8_t rtnBytes[3];
  memcpy(rtnBytes, rtnStr.c_str(), 3);
  uint8_t* hmac = HMACHelper(rtnBytes, 3, LocalMacHashed, RandIV);
  if (!hmac) {
    Serial.println("[X] Failed to generate HMAC for ACK");
    free(RandIV);
    return;
  }
  LoRa.beginPacket();
    LoRa.write(3);             // setup bit 3 = ACK
    LoRa.write(rtnBytes, 3);  // RTN code as 3-byte string
    LoRa.write(RandIV, 16);   // IV
    LoRa.write(hmac, 32);     // HMAC
  LoRa.endPacket();
  Serial.printf("[*] ACK sent: %d\n", rtn);
  free(hmac);
  free(RandIV);
}

  // send handshake via LoRa
  // Wire format: [Setup 1B][pubkey size 1B][pubkey N B][senderMAC 8B][KeyReturn 1B]
  // Sender MAC is included so the receiver can recompute the salted MAC digest after a
  // cold reboot, when raw RemotemacInt is no longer in RAM (NVS now holds only the digest).
void TransmitLoRaHandshake(int Setup,int payloadSize, uint8_t* payload, int KeyReturn){
  uint8_t macBytes[8];
  for (int i = 0; i < 8; i++) macBytes[i] = (LocalMacInt_global >> (56 - i*8)) & 0xFF;
  LoRa.beginPacket();
    LoRa.write(Setup);
    LoRa.write(payloadSize);
    LoRa.write(payload,payloadSize);
    LoRa.write(macBytes, 8);
    LoRa.write(KeyReturn);
  LoRa.endPacket();
}

  // receive LoRa payload
void onReceive(int packetSize){
  if (!packetSize) return; //Drop packet
  if (packetSize > MAX_PAYLOAD_SIZE || packetSize <= 0) { //drop package if package size is larger then 255
    Serial.println("[X] Invalid payload size");
    return;
  }
    float RSSI_pre = (1.0 - (-1*LoRa.packetRssi())/125.0) * 100.0;
    Serial.printf("[*] LoRa Packet size: %d  ,SNR: %f  , signal: %f %%\n", packetSize, LoRa.packetSnr(), RSSI_pre); //print to serial
    // Reading package
  int SetupParam = LoRa.read(); // setup bit
  uint8_t PrefRemoteMacHashed[32] = {0};
  preferences.getBytes(RemoteMACHash.c_str(), PrefRemoteMacHashed, 32); // get salted remote-MAC digest
  switch (SetupParam) {
    case 0:{//LoRa handshake
      Serial.println("[*] LoRa handshake received");
      int RecKeySize = LoRa.read();
      uint8_t RecPubKey[RecKeySize];
      for (int i = 0; i < RecKeySize; i++) {
        RecPubKey[i] = LoRa.read();  //read remote public key
      }
      // Read sender MAC so we can salt-hash it with the fresh HashSecret.
      RemotemacInt = 0;
      for (int i = 0; i < 8; i++) {
        RemotemacInt = (RemotemacInt << 8) | (uint8_t)LoRa.read();
      }
      Serial.printf("[V] Handshake sender MAC int: %llu\n", RemotemacInt);
      RemoteKeyReceivedProcess(RecPubKey);
      Serial.println("[*] onReceive remote public key received");
      int KeySend = LoRa.read();
      if ((bool)KeySend){ // if send key (if remote hash secret = 0) = 1 then resend public key
        Serial.println("[*] onReceive ,KeySend = 1, sending local public key");
        TransmitLoRaHandshake(0, 32, publicKey,0);
      }
      TransmitLoRaACK(RTN_RESYNC); // Notify sender that key sync was received
      break;
    }
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

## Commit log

2026-05-01 Add README for 3D enclosure case project
2026-05-01 Add README for GERBER project
2026-05-08 Add files via upload
    3D ready to print enclosure and assembly
    [260506 Top cover.3mf, 260508 Bottom cover.3mf]
